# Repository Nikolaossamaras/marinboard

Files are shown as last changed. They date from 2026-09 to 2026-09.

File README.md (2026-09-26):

# MariBoard
>A costum keyboard featuring the anime Character Marin Kitagawa

## What is it
It's a costum keyboard with the thematic of Marin kitagawa from the anime My-dress-up-darling by cloverworks. It's layout is keycool kc84 75% . It includes 84 keys & an oled diplay and it's powered by in raspberry pi pico W , allowing it to connect to the internet in order to display information to the oled display like the Time , date & Weather

## Why i built it?

I really love anime and my favourite character is Marin Kitagawa. I also like electronics and making projects so i sat down and though which will be my next project and i decided on this one a CUSTOM KEYBOARD that is designed with diffrent Marin Kitagawa and dress-up-darling pictures.

## PCB Preview
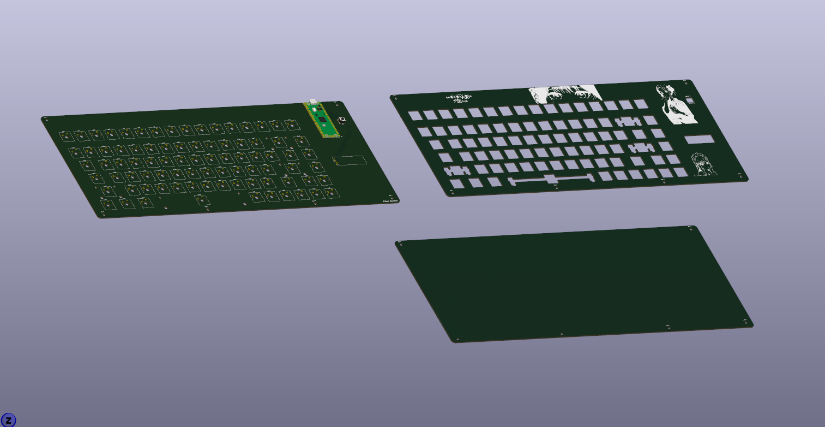
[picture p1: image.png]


---

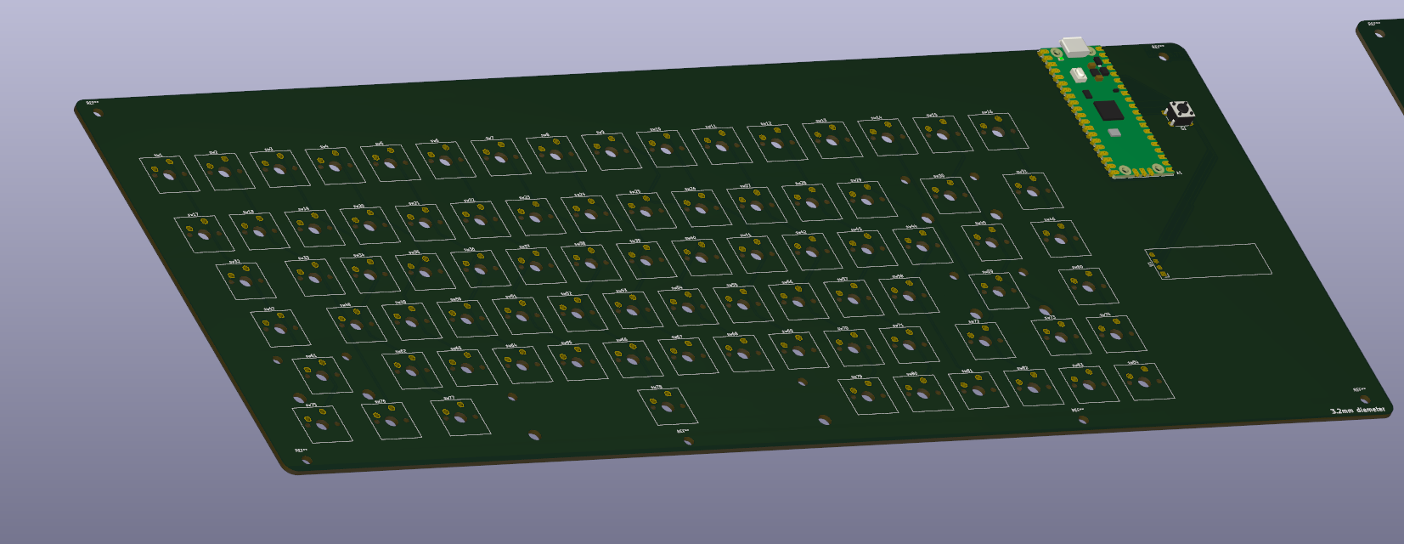
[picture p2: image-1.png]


## Schematic
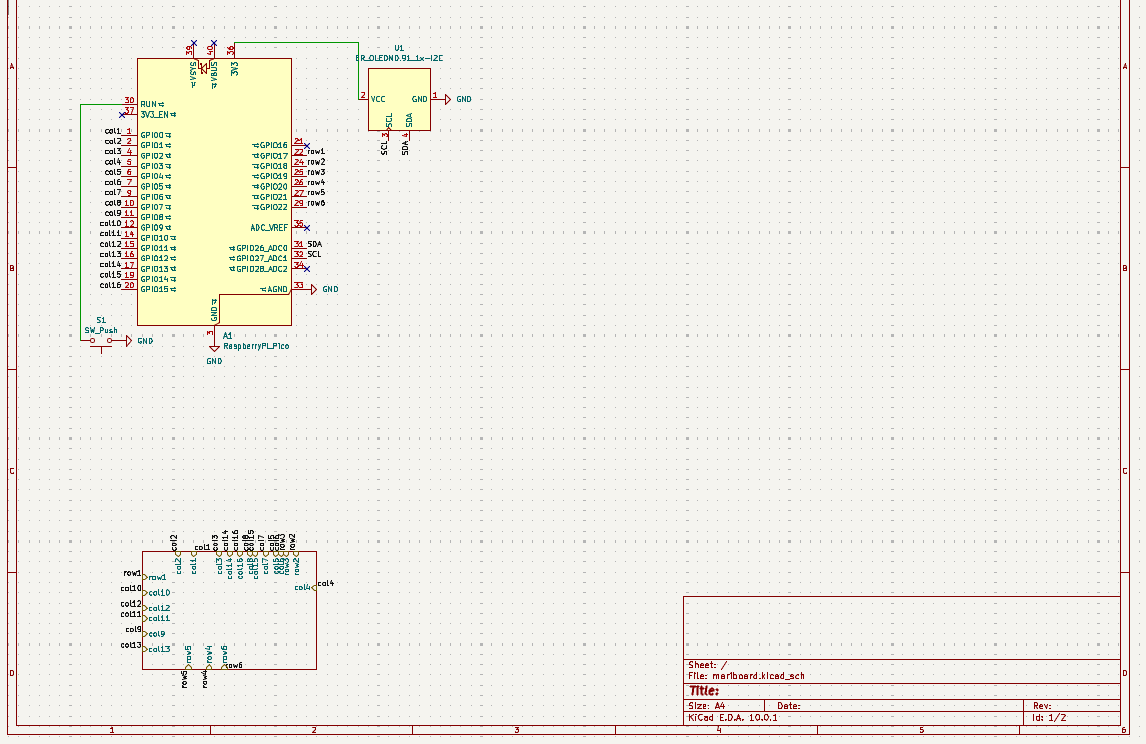
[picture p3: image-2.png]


---

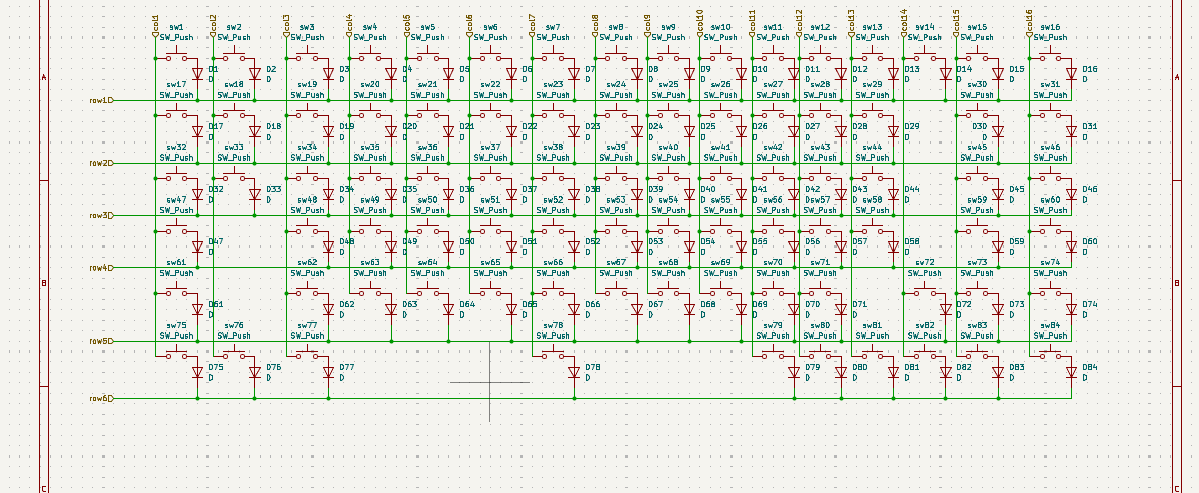
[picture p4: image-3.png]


## CAD



## PCB assembly


## Requirements

| Product | quantity |
| --- | --- |
| OLED Module 128x32 0.91" i2c | 1pc |
| Raspberry Pi Pico W | 1pc |
| 1N4148W diodes | 84pcs |
| costum pcb | 1pc |
| cherry mx switches | 84pcs |
| keycaps | 84 pcs |
| knurled nuts brass m3 | 4pcs |
| 3D printed case | 1pc |

## Tools 

| Tool |
| --- |
| soldering station/iron |
| 3d printer |

## How to assemble it?

### 1st step
your first step is cloning this repo to your Pc so you have all the required files

### 2nd step

Get your pcb , go to a pcb production company and upload the gerber.zip file on their site and order the board

### 3rd step

While you wait for your pcb you can start 3d printing your case which is in Cad folder, there you will see 2 files both are the same one but diffrent format.

> if you don't have a 3d printer you can 3d print it from the same company from which you ordered your pcb

### 4th step 

Now that you have the pcb you will need to solder everything together
if you get an assembled board you wont need to solder the diodes as the are already will come installed , but if you didn't 
your next step is to solder the diodes together on the board like instructed in the schematic

### 5th step
when you finish with the diodes check them with a multimeter to check if they are connected the correct way

### 6th step
now solder the microcontroller and the push button

### 7th step 
solder the oled display in place

### 8th step 
add the switches to the top pcb in order and then put it on top of the middle pcb(main pcb), be careful to align every switch correctly in order the soldering of them to procced smoothly

### 9th step 
add nuts to the 3d printed case at the button 
then place on top of it the pcb's in order (first the bottom , then the main and then the top one) after that pass a screw in each corner mounting hole of the pcb until it's reached the nut , be careful not to damage the main board

### 10th step 
You will need to download the latest .uf2 stable file on Circuitpython for pico W (make sure it's the W not the normal version)

### 11th step
hold the bootsel button on the board while inserting the board to your pc release the button when it's connected **do this step before soldering the top and main pcb together**

### 12th step 

copy the .uf2 file to the microcontroller

the board will reboot and then a drove called ```Circuitpython``` should appear 

### 13th step
Your main program must be named code.py (or main.py) and placed at the root of CIRCUITPY
For libraries , grab the matching version of the CircuitPython Library Bundle and copy the needed .mpy files into a /lib folder on CIRCUITPY

### 14th step
when you upload the code to the drive it should become an input meaning the drive will disapear

## Licence

This project is under the MIT licence

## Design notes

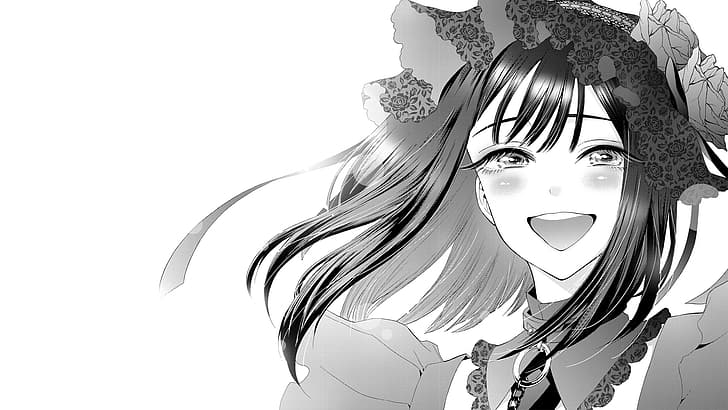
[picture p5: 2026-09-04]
manga-anime-anime-girls-monochrome-sono-bisque-doll-wa-koi-wo-suru-hd-wallpaper-preview.jpg

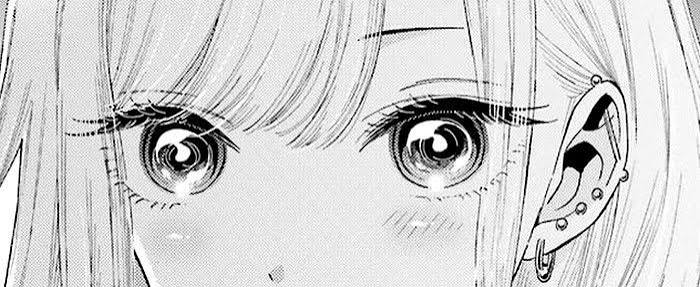
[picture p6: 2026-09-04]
images (1).jpg

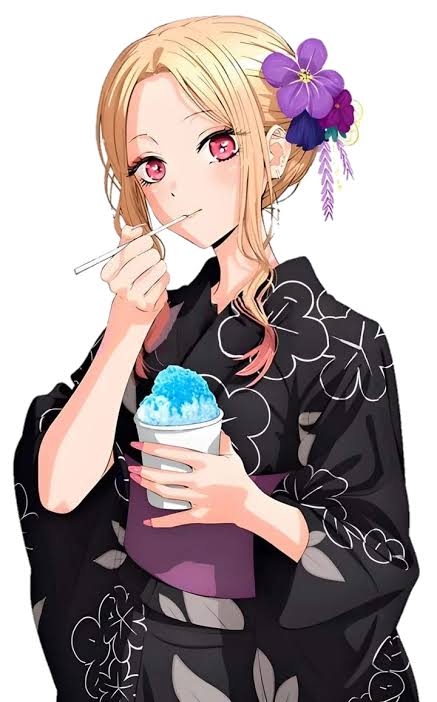
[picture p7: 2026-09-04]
images (2).jpg

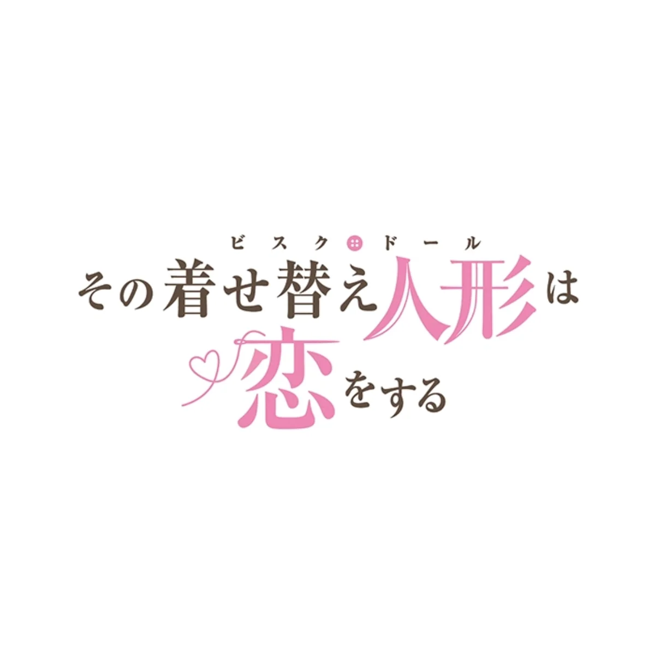
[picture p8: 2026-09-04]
text.png.webp

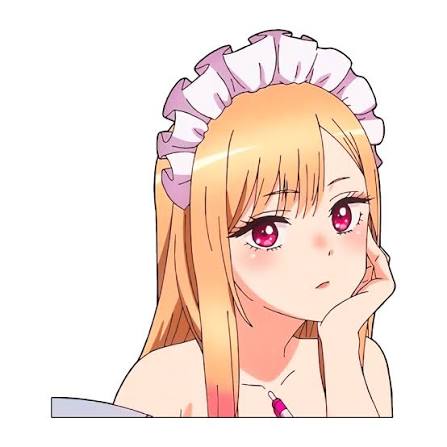
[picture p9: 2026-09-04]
images (3).jpg

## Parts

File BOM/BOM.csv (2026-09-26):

PRODUCT | price | link
OLED Module 0.91" 128x32 - I2C White | 7,90Â $ | https://grobotronics.com/oled-module-0.91-128x32-i2c-white.html
Raspberry Pi Pico W | 9,29Â $ | https://grobotronics.com/raspberry-pi-pico-w-wireless.html?variation_id=16653
1N4148W | $2.06 | https://www.lcsc.com/product-detail/C84367.html?s_z=n_q_x_1N4148W%2520
pcb | $69.28
cherry mx switch | 11.56$ | https://www.temu.com/goods.html?_bg_fs=1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
keycaps | 7.52$ | https://www.temu.com/goods.html?_bg_fs=1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"ld"%2C"US"&_x_ads_channel=impact&_x_ns_mp_value2=&_x_ns_mp_value3=&_x_ns_irmpname=Opera%E2%80%8A&_x_ns_irpid=1943907&_x_vst_scene=adg&_x_sessn_id=80e3cu2gu0&refer_page_name=shopping_cart&refer_page_id=10037_1790422392073_kwofvvozaw&refer_page_sn=10037
knurled nuts brass m3 | 6,57 $ | https://www.temu.com/goods.html?_bg_fs=1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
total | 114.18

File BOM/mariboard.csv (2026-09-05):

Reference | Qty | Value | DNP | Exclude from BOM | Exclude from Board | Exclude from Simulation | Exclude from Position Files | Footprint | Datasheet
A1 | 1 | RaspberryPi_Pico |  |  |  |  | ${EXCLUDE_FROM_POS_FILES} | Module:RaspberryPi_Pico_Common_Unspecified | https://datasheets.raspberrypi.com/pico/pico-datasheet.pdf
D1,D2,D3,D4,D5,D6,D7,D8,D9,D10,D11,D12,D13,D14,D15,D16,D17,D18,D19,D20,D21,D22,D23,D24,D25,D26,D27,D28,D29,D30,D31,D32,D33,D34,D35,D36,D37,D38,D39,D40,D41,D42,D43,D44,D45,D46,D47,D48,D49,D50,D51,D52,D53,D54,D55,D56,D57,D58,D59,D60,D61,D62,D63,D64,D65,D66,D67,D68,D69,D70,D71,D72,D73,D74,D75,D76,D77,D78,D79,D80,D81,D82,D83,D84 | 84 | D |  |  |  |  | ${EXCLUDE_FROM_POS_FILES} | Diode_SMD:D_SOD-123
S1 | 1 | SW_Push |  |  |  |  | ${EXCLUDE_FROM_POS_FILES} | Button_Switch_THT:SW_PUSH_6mm
sw1,sw2,sw3,sw4,sw5,sw6,sw7,sw8,sw9,sw10,sw11,sw12,sw13,sw14,sw15,sw16,sw17,sw18,sw19,sw20,sw21,sw22,sw23,sw24,sw25,sw26,sw27,sw28,sw29,sw31,sw33,sw34,sw35,sw36,sw37,sw38,sw39,sw40,sw41,sw42,sw43,sw44,sw46,sw48,sw49,sw50,sw51,sw52,sw53,sw54,sw55,sw56,sw57,sw58,sw60,sw62,sw63,sw64,sw65,sw66,sw67,sw68,sw69,sw70,sw71,sw73,sw74,sw79,sw80,sw81,sw82,sw83,sw84 | 73 | SW_Push |  |  |  |  | ${EXCLUDE_FROM_POS_FILES} | Button_Switch_Keyboard:SW_Cherry_MX_1.00u_PCB
sw30 | 1 | SW_Push |  |  |  |  | ${EXCLUDE_FROM_POS_FILES} | Button_Switch_Keyboard:SW_Cherry_MX_2.00u_PCB
sw32,sw45 | 2 | SW_Push |  |  |  |  | ${EXCLUDE_FROM_POS_FILES} | Button_Switch_Keyboard:SW_Cherry_MX_1.50u_PCB
sw47,sw72 | 2 | SW_Push |  |  |  |  | ${EXCLUDE_FROM_POS_FILES} | Button_Switch_Keyboard:SW_Cherry_MX_1.75u_PCB
sw59,sw61 | 2 | SW_Push |  |  |  |  | ${EXCLUDE_FROM_POS_FILES} | Button_Switch_Keyboard:SW_Cherry_MX_2.25u_PCB
sw75,sw76,sw77 | 3 | SW_Push |  |  |  |  | ${EXCLUDE_FROM_POS_FILES} | Button_Switch_Keyboard:SW_Cherry_MX_1.25u_PCB
sw78 | 1 | SW_Push |  |  |  |  | ${EXCLUDE_FROM_POS_FILES} | Button_Switch_Keyboard:SW_Cherry_MX_6.25u_PCB
U1 | 1 | ER_OLEDM0.91_1x-I2C |  |  |  |  | ${EXCLUDE_FROM_POS_FILES} | Display:ER_OLEDM0.91_1x-I2C | https://www.buydisplay.com/download/manual/ER-OLEDM0.91-1_Datasheet.pdf

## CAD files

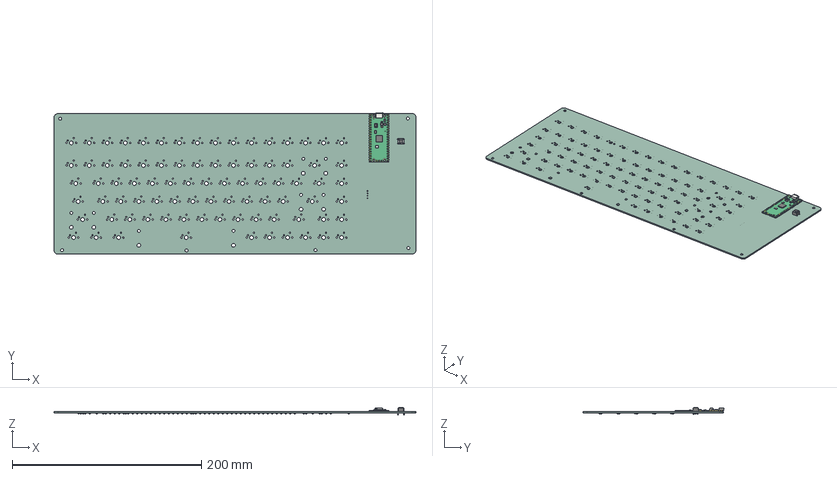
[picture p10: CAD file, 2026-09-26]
Cad/mainv2.step
382.7 x 149.6 x 7.80 mm
SW_PUSH_6mm
RaspberryPi_Pico_Module_KiCad
D_SOD-123 x 84
mariboard_PCB

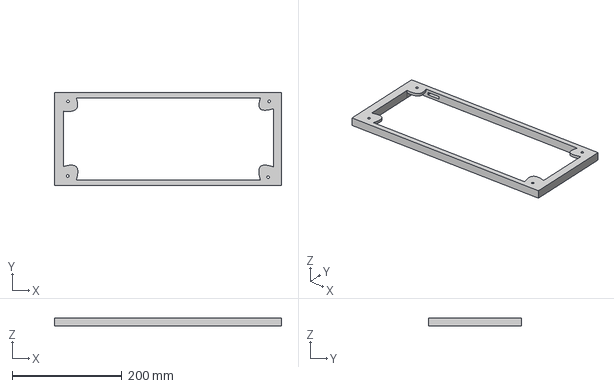
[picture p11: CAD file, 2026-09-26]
Cad/case keyboard mariboard.step
413.0 x 169.0 x 15.0 mm

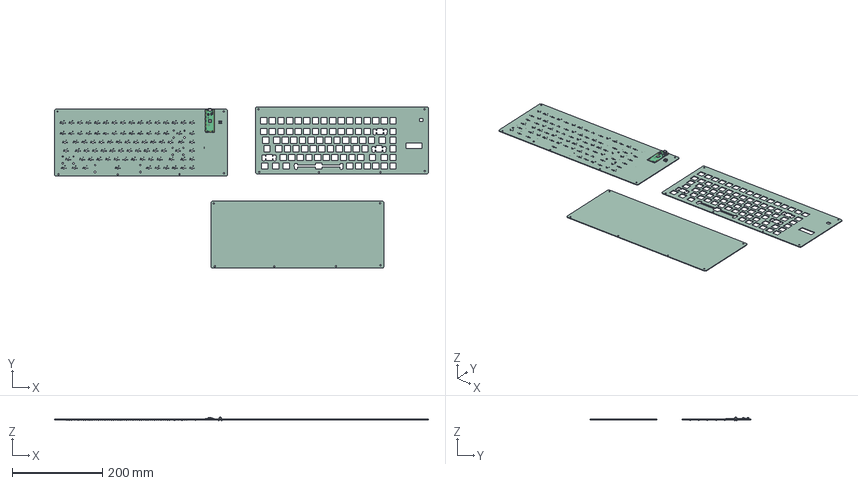
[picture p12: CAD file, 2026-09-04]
Cad/mariboard.step
827.0 x 356.9 x 7.80 mm
SW_PUSH_6mm
RaspberryPi_Pico_Module_KiCad
D_SOD-123 x 84
marCF42_PCB_1
marCF42_PCB_2
marCF42_PCB_3

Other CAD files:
Cad/case keyboard mariboard.f3d
Cad/pcb_assembly.f3z

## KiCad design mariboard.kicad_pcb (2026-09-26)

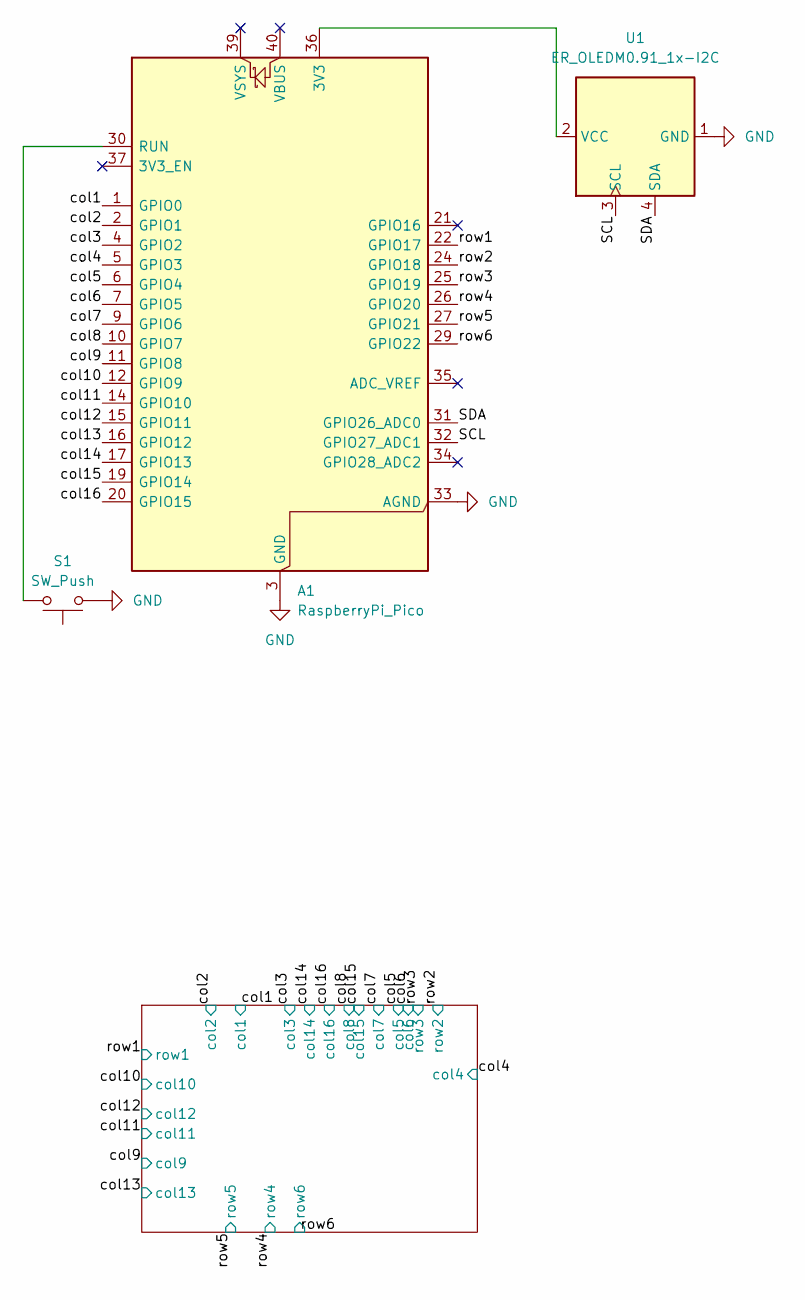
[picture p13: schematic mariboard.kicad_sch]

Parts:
A1: RaspberryPi_Pico; RaspberryPi_Pico_Common_Unspecified
S1: SW_Push; SW_PUSH_6mm
U1: ER_OLEDM0.91_1x-I2C

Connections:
/SCL: A1.32 (GPIO27_ADC1), U1.3 (SCL)
/SDA: A1.31 (GPIO26_ADC0), U1.4 (SDA)
/col1: A1.1 (GPIO0); also elsewhere on the board
/col2: A1.2 (GPIO1); also elsewhere on the board
/col3: A1.4 (GPIO2); also elsewhere on the board
/col4: A1.5 (GPIO3); also elsewhere on the board
/col5: A1.6 (GPIO4); also elsewhere on the board
/col6: A1.7 (GPIO5); also elsewhere on the board
/col7: A1.9 (GPIO6); also elsewhere on the board
/col8: A1.10 (GPIO7); also elsewhere on the board
/col9: A1.11 (GPIO8); also elsewhere on the board
/col10: A1.12 (GPIO9); also elsewhere on the board
/col11: A1.14 (GPIO10); also elsewhere on the board
/col12: A1.15 (GPIO11); also elsewhere on the board
/col13: A1.16 (GPIO12); also elsewhere on the board
/col14: A1.17 (GPIO13); also elsewhere on the board
/col15: A1.19 (GPIO14); also elsewhere on the board
/col16: A1.20 (GPIO15); also elsewhere on the board
/row1: A1.22 (GPIO17); also elsewhere on the board
/row2: A1.24 (GPIO18); also elsewhere on the board
/row3: A1.25 (GPIO19); also elsewhere on the board
/row4: A1.26 (GPIO20); also elsewhere on the board
/row5: A1.27 (GPIO21); also elsewhere on the board
/row6: A1.29 (GPIO22); also elsewhere on the board
GND: A1.3 (GND), A1.8 (GND), A1.13 (GND), A1.18 (GND), A1.23 (GND), A1.28 (GND), A1.33 (AGND), A1.38 (GND), S1.1, U1.1 (GND)
unnamed: A1.36 (3V3), U1.2 (VCC)
unnamed: A1.30 (RUN), S1.2

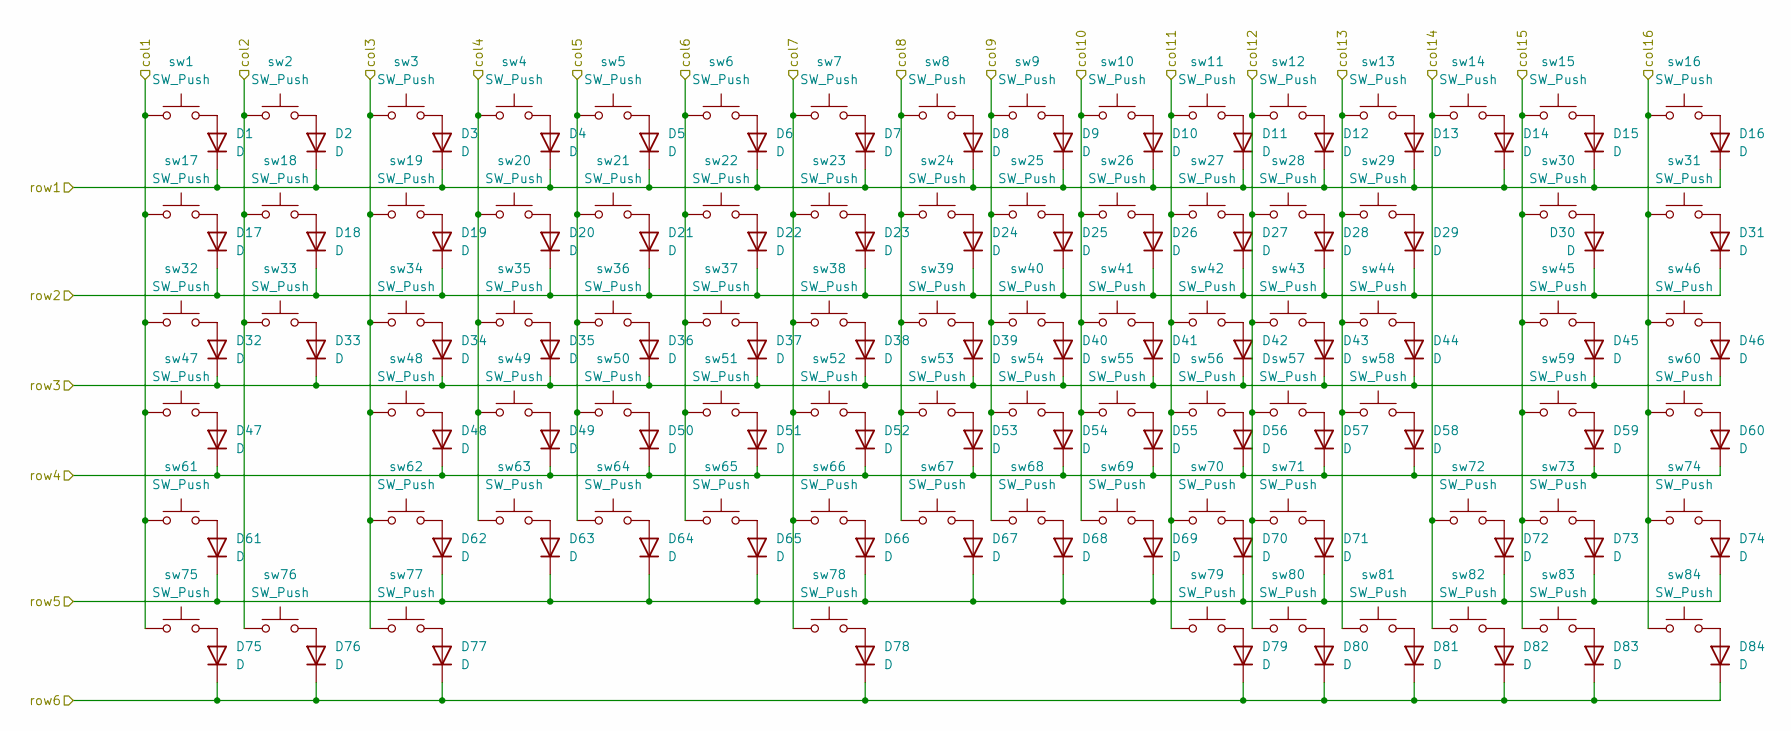
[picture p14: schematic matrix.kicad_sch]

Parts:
D1, D2, D3, D4, D5, D6, D7, D8, D9, D10, D11, D12, D13, D14, D15, D16, D17, D18, D19, D20, D21, D22, D23, D24, D25, D26, D27, D28, D29, D30, D31, D32, D33, D34, D35, D36, D37, D38, D39, D40, D41, D42, D43, D44, D45, D46, D47, D48, D49, D50, D51, D52, D53, D54, D55, D56, D57, D58, D59, D60, D61, D62, D63, D64, D65, D66, D67, D68, D69, D70, D71, D72, D73, D74, D75, D76, D77, D78, D79, D80, D81, D82, D83, D84: D; D_SOD-123
sw1, sw2, sw3, sw4, sw5, sw6, sw7, sw8, sw9, sw10, sw11, sw12, sw13, sw14, sw15, sw16, sw17, sw18, sw19, sw20, sw21, sw22, sw23, sw24, sw25, sw26, sw27, sw28, sw29, sw31, sw33, sw34, sw35, sw36, sw37, sw38, sw39, sw40, sw41, sw42, sw43, sw44, sw46, sw48, sw49, sw50, sw51, sw52, sw53, sw54, sw55, sw56, sw57, sw58, sw60, sw62, sw63, sw64, sw65, sw66, sw67, sw68, sw69, sw70, sw71, sw73, sw74, sw79, sw80, sw81, sw82, sw83, sw84: SW_Push; SW_Cherry_MX_1.00u_PCB
sw30: SW_Push; SW_Cherry_MX_2.00u_PCB
sw32, sw45: SW_Push; SW_Cherry_MX_1.50u_PCB
sw47, sw72: SW_Push; SW_Cherry_MX_1.75u_PCB
sw59, sw61: SW_Push; SW_Cherry_MX_2.25u_PCB
sw75, sw76, sw77: SW_Push; SW_Cherry_MX_1.25u_PCB
sw78: SW_Push; SW_Cherry_MX_6.25u_PCB

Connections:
/col1: sw1.1, sw17.1, sw32.1, sw47.1, sw61.1, sw75.1; also elsewhere on the board
/col2: sw2.1, sw18.1, sw33.1, sw76.1; also elsewhere on the board
/col3: sw3.1, sw19.1, sw34.1, sw48.1, sw62.1, sw77.1; also elsewhere on the board
/col4: sw4.1, sw20.1, sw35.1, sw49.1, sw63.1; also elsewhere on the board
/col5: sw5.1, sw21.1, sw36.1, sw50.1, sw64.1; also elsewhere on the board
/col6: sw6.1, sw22.1, sw37.1, sw51.1, sw65.1; also elsewhere on the board
/col7: sw7.1, sw23.1, sw38.1, sw52.1, sw66.1, sw78.1; also elsewhere on the board
/col8: sw8.1, sw24.1, sw39.1, sw53.1, sw67.1; also elsewhere on the board
/col9: sw9.1, sw25.1, sw40.1, sw54.1, sw68.1; also elsewhere on the board
/col10: sw10.1, sw26.1, sw41.1, sw55.1, sw69.1; also elsewhere on the board
/col11: sw11.1, sw27.1, sw42.1, sw56.1, sw70.1, sw79.1; also elsewhere on the board
/col12: sw12.1, sw28.1, sw43.1, sw57.1, sw71.1, sw80.1; also elsewhere on the board
/col13: sw13.1, sw29.1, sw44.1, sw58.1, sw81.1; also elsewhere on the board
/col14: sw14.1, sw72.1, sw82.1; also elsewhere on the board
/col15: sw15.1, sw30.1, sw45.1, sw59.1, sw73.1, sw83.1; also elsewhere on the board
/col16: sw16.1, sw31.1, sw46.1, sw60.1, sw74.1, sw84.1; also elsewhere on the board
/row1: D1.1 (K), D2.1 (K), D3.1 (K), D4.1 (K), D5.1 (K), D6.1 (K), D7.1 (K), D8.1 (K), D9.1 (K), D10.1 (K), D11.1 (K), D12.1 (K), D13.1 (K), D14.1 (K), D15.1 (K), D16.1 (K); also elsewhere on the board
/row2: D17.1 (K), D18.1 (K), D19.1 (K), D20.1 (K), D21.1 (K), D22.1 (K), D23.1 (K), D24.1 (K), D25.1 (K), D26.1 (K), D27.1 (K), D28.1 (K), D29.1 (K), D30.1 (K), D31.1 (K); also elsewhere on the board
/row3: D32.1 (K), D33.1 (K), D34.1 (K), D35.1 (K), D36.1 (K), D37.1 (K), D38.1 (K), D39.1 (K), D40.1 (K), D41.1 (K), D42.1 (K), D43.1 (K), D44.1 (K), D45.1 (K), D46.1 (K); also elsewhere on the board
/row4: D47.1 (K), D48.1 (K), D49.1 (K), D50.1 (K), D51.1 (K), D52.1 (K), D53.1 (K), D54.1 (K), D55.1 (K), D56.1 (K), D57.1 (K), D58.1 (K), D59.1 (K), D60.1 (K); also elsewhere on the board
/row5: D61.1 (K), D62.1 (K), D63.1 (K), D64.1 (K), D65.1 (K), D66.1 (K), D67.1 (K), D68.1 (K), D69.1 (K), D70.1 (K), D71.1 (K), D72.1 (K), D73.1 (K), D74.1 (K); also elsewhere on the board
/row6: D75.1 (K), D76.1 (K), D77.1 (K), D78.1 (K), D79.1 (K), D80.1 (K), D81.1 (K), D82.1 (K), D83.1 (K), D84.1 (K); also elsewhere on the board
unnamed: D1.2 (A), sw1.2
unnamed: D2.2 (A), sw2.2
unnamed: D3.2 (A), sw3.2
unnamed: D4.2 (A), sw4.2
unnamed: D5.2 (A), sw5.2
unnamed: D6.2 (A), sw6.2
unnamed: D7.2 (A), sw7.2
unnamed: D8.2 (A), sw8.2
unnamed: D9.2 (A), sw9.2
unnamed: D10.2 (A), sw10.2
unnamed: D11.2 (A), sw11.2
unnamed: D12.2 (A), sw12.2
unnamed: D13.2 (A), sw13.2
unnamed: D14.2 (A), sw14.2
unnamed: D15.2 (A), sw15.2
unnamed: D16.2 (A), sw16.2
unnamed: D17.2 (A), sw17.2
unnamed: D18.2 (A), sw18.2
unnamed: D19.2 (A), sw19.2
unnamed: D20.2 (A), sw20.2
unnamed: D21.2 (A), sw21.2
unnamed: D22.2 (A), sw22.2
unnamed: D23.2 (A), sw23.2
unnamed: D24.2 (A), sw24.2
unnamed: D25.2 (A), sw25.2
unnamed: D26.2 (A), sw26.2
unnamed: D27.2 (A), sw27.2
unnamed: D28.2 (A), sw28.2
unnamed: D29.2 (A), sw29.2
unnamed: D30.2 (A), sw30.2
unnamed: D31.2 (A), sw31.2
unnamed: D32.2 (A), sw32.2
unnamed: D33.2 (A), sw33.2
unnamed: D34.2 (A), sw34.2
unnamed: D35.2 (A), sw35.2
unnamed: D36.2 (A), sw36.2
unnamed: D37.2 (A), sw37.2
unnamed: D38.2 (A), sw38.2
unnamed: D39.2 (A), sw39.2
unnamed: D40.2 (A), sw40.2
unnamed: D41.2 (A), sw41.2
unnamed: D42.2 (A), sw42.2
unnamed: D43.2 (A), sw43.2
unnamed: D44.2 (A), sw44.2
unnamed: D45.2 (A), sw45.2
unnamed: D46.2 (A), sw46.2
unnamed: D47.2 (A), sw47.2
unnamed: D48.2 (A), sw48.2
unnamed: D49.2 (A), sw49.2
unnamed: D50.2 (A), sw50.2
unnamed: D51.2 (A), sw51.2
unnamed: D52.2 (A), sw52.2
unnamed: D53.2 (A), sw53.2
unnamed: D54.2 (A), sw54.2
unnamed: D55.2 (A), sw55.2
unnamed: D56.2 (A), sw56.2
unnamed: D57.2 (A), sw57.2
unnamed: D58.2 (A), sw58.2
unnamed: D59.2 (A), sw59.2
unnamed: D60.2 (A), sw60.2
unnamed: D61.2 (A), sw61.2
unnamed: D62.2 (A), sw62.2
unnamed: D63.2 (A), sw63.2
unnamed: D64.2 (A), sw64.2
unnamed: D65.2 (A), sw65.2
unnamed: D66.2 (A), sw66.2
unnamed: D67.2 (A), sw67.2
unnamed: D68.2 (A), sw68.2
unnamed: D69.2 (A), sw69.2
unnamed: D70.2 (A), sw70.2
unnamed: D71.2 (A), sw71.2
unnamed: D72.2 (A), sw72.2
unnamed: D73.2 (A), sw73.2
unnamed: D74.2 (A), sw74.2
unnamed: D75.2 (A), sw75.2
unnamed: D76.2 (A), sw76.2
unnamed: D77.2 (A), sw77.2
unnamed: D78.2 (A), sw78.2
unnamed: D79.2 (A), sw79.2
unnamed: D80.2 (A), sw80.2
unnamed: D81.2 (A), sw81.2
unnamed: D82.2 (A), sw82.2
unnamed: D83.2 (A), sw83.2
unnamed: D84.2 (A), sw84.2

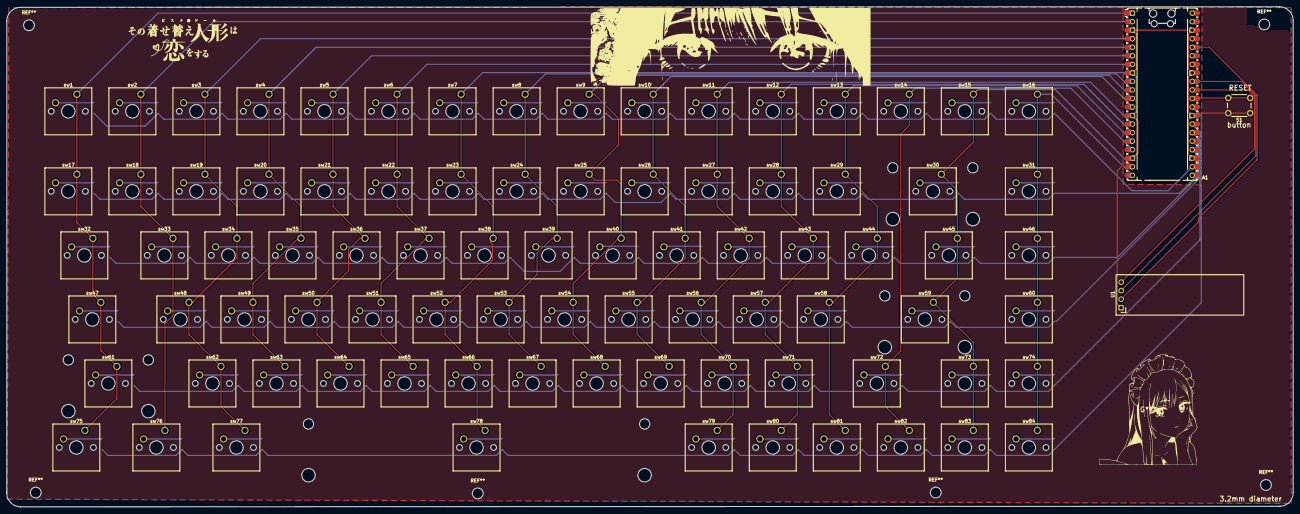
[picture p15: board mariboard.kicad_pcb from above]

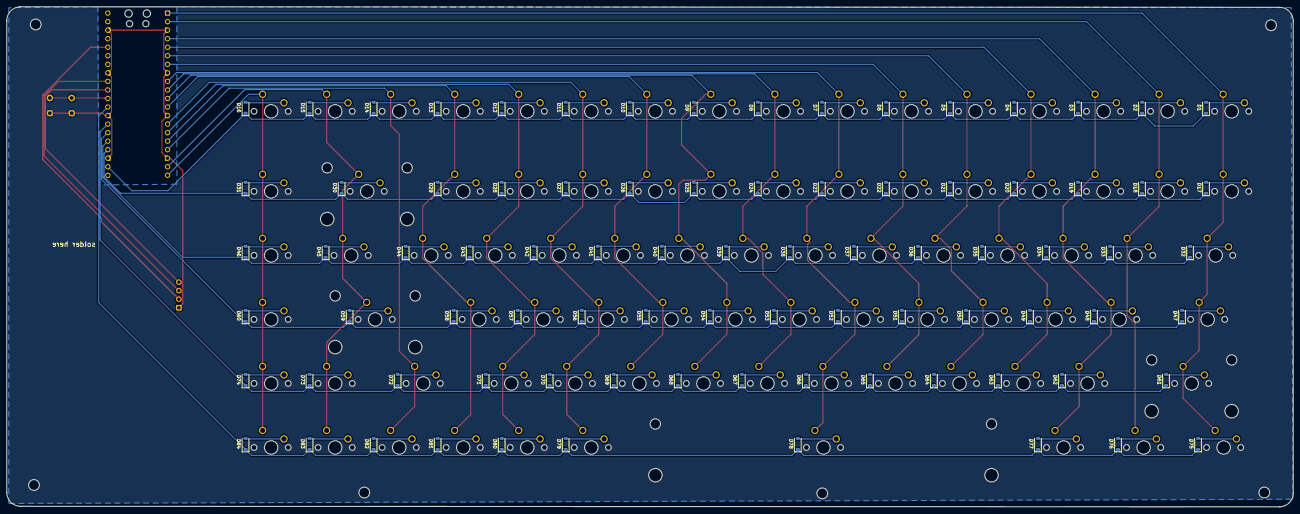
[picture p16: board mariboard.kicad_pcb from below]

Board: 2 copper layers, 382.7 x 148.8 mm, 171 parts (84 on the bottom side), 111 nets.

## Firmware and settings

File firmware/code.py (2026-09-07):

import board
import digitalio
import usb_hid
import time
import busio
import displayio
import terminalio
import wifi
import socketpool
import ssl
import os
import rtc
import adafruit_requests
import adafruit_ntp
import adafruit_displayio_ssd1306

from adafruit_display_text import label
from adafruit_hid.keyboard import Keyboard
from adafruit_hid.keycode import Keycode

#Configuration

WIFI_SSID = os.getenv("WIFI_SSID") # change this in your .env file
WIFI_PASSWORD = os.getenv("WIFI_PASSWORD") # change this in your .env file
WIFI_TIMEOUT = 8  

UTC_OFFSET = 3

OPENWEATHER_API_KEY = os.getenv("OPENWEATHER_API_KEY") # change this in your .env file
OPENWEATHER_CITY = "Athens,GR" # change this to your city
WEATHER_REFRESH_TIME = 900 

NTP_REFRESH_RATE = 3600

ANIMATION_FRAME_DIR= "/marin"
ANIMATION_FRAME_COUNT = 56
ANIMATION_FRAME_INTERVAL = 0.15

OLED_WIDTH = 128
OLED_HEIGHT = 32
OLED_I2C_ADDRESS = 0x3C
SDA_PIN = board.GP26
SCL_PIN = board.GP27

COL_PINS =[
    board.GP0,
    board.GP1,
    board.GP2,
    board.GP3,
    board.GP4,
    board.GP5,
    board.GP6,
    board.GP7,
    board.GP8,
    board.GP9,
    board.GP10,
    board.GP11,
    board.GP12,
    board.GP13,
    board.GP14,
    board.GP15
]#columns 1-16

ROW_PINS = [
    board.GP17,
    board.GP18,
    board.GP19,
    board.GP20,
    board.GP21,
    board.GP22
]#rows 1-6

columns =[]

for pin in COL_PINS:
    col = digitalio.DigitalInOut(pin)
    col.direction = digitalio.Direction.OUTPUT
    col.value = False
    columns.append(col)
rows = []

for pin in ROW_PINS:
    row = digitalio.DigitalInOut(pin)
    row.direction = digitalio.Direction.INPUT
    row.pull = digitalio.Pull.DOWN
    rows.append(row)


displayio.release_displays()
i2c= busio.I2C(SCL_PIN,SDA_PIN)
display_bus = displayio.I2CDisplay(i2c, device_address=OLED_I2C_ADDRESS)
display = adafruit_displayio_ssd1306.SSD1306(display_bus,width=OLED_WIDTH,height=OLED_HEIGHT)


# PAGE 1


_reported_missing = set()
animation_group = displayio.Group()
_current_frame_bitmap = None
_current_frame_tilegrid = None

def load_animation_frame(index):
    global _current_frame_bitmap, _current_frame_tilegrid

    path = "{}/frame{:03d}.bmp".format(ANIMATION_FRAME_DIR, index + 1)
    try:
        bitmap = displayio.OnDiskBitmap(path)
    except OSError:
        if path not in _reported_missing:
            print("Failed to load frame:",path)
            _reported_missing.add(path)
        return

    tilegrid = displayio.TileGrid(bitmap, pixel_shader=bitmap.pixel_shader)

    if _current_frame_tilegrid is not None:
        animation_group.remove(_current_frame_tilegrid)

    animation_group.append(tilegrid)
    _current_frame_bitmap = bitmap
    _current_frame_tilegrid = tilegrid

# Page 2
clock_group = displayio.Group()
clock_time_label = label.Label(terminalio.FONT, text="--:--:--",x=25,y=8,scale =1)
clock_group.append(clock_time_label)
clock_date_label = label.Label(terminalio.FONT, text="--/--/----",x=25,y=20,scale =1)
clock_group.append(clock_date_label)

# Page 3
weather_group = displayio.Group()
weather_temp_label = label.Label(terminalio.FONT, text="--°C",x=5,y=8,scale =1)
weather_group.append(weather_temp_label)
weather_cond_label = label.Label(terminalio.FONT,text="---",x=60,y=8,scale =1)
weather_group.append(weather_cond_label)
weather_hum_label = label.Label(terminalio.FONT,text="--%",x=5,y=22,scale =1)
weather_group.append(weather_hum_label)

PAGES =[animation_group, clock_group, weather_group]
current_page_index = 0
display.root_group = PAGES[current_page_index]

# WIFI

wifi_connected = False
requests_session = None
ntp = None

try:
    wifi.radio.connect(WIFI_SSID, WIFI_PASSWORD, timeout=WIFI_TIMEOUT)
    wifi_connected = True
except (ConnectionError, OSError):
    wifi_connected = False

if wifi_connected:
    pool = socketpool.SocketPool(wifi.radio)
    requests_session = adafruit_requests.Session(pool, ssl.create_default_context())
    ntp = adafruit_ntp.NTP(pool, tz_offset=UTC_OFFSET)

# States

now=time.monotonic()

last_animation_tick = now
animation_frame_index = 0

last_clock_update = 0
last_ntp_sync = 0
time_synced = False

last_weather_fetch = 0
weather_ok = False

WEEKDAYS = ["Mon","Tue","Wed","Thu","Fri","Sat","Sun"]

def sync_ntp_time():
    global time_synced
    if not  wifi_connected or ntp is None:
        return
    try:
        rtc.RTC().datetime = ntp.datetime
        time_synced = True
    except(ValueError,OSError):
        time_synced = False

def fetch_weather():
    global weather_ok
    if not wifi_connected or requests_session is None:
        weather_ok = False
        return None
    url=(
        "https://api.openweathermap.org/data/2.5/weather"
        "?q={city}&appid={key}&units=metric"
    ).format(city=OPENWEATHER_CITY,key=OPENWEATHER_API_KEY)
    try:
        response = requests_session.get(url,timeout=5)
        data = response.json()
        response.close()
        weather_ok = True
        return{
            "temp": data["main"]["temp"],
            "humidity": data["main"]["humidity"],
            "condition": data["weather"][0]["main"]
        }
    except (OSError,ValueError,KeyError):
        weather_ok = False
        return None

def update_clock_display():
    t = time.localtime()
    time_str = "{:02d}:{:02d}:{:02d}".format(t.tm_hour,t.tm_min,t.tm_sec)
    date_str = "{:02d}/{:02d}/{:04d}".format(t.tm_mday,t.tm_mon,t.tm_year)

    if clock_time_label.text != time_str:
        clock_time_label.text = time_str
    if clock_date_label.text != date_str:
        clock_date_label.text = date_str

def update_weather_display(weather):
    if weather is None:
        weather_cond_label.text = "Offline"
        return
    weather_temp_label.text = "{:.1f}C".format(weather["temp"])
    weather_cond_label.text = weather["condition"]
    weather_hum_label.text = "Hum: {}%".format(weather["humidity"])

def switch_page():
    global current_page_index
    current_page_index = (current_page_index + 1) % len(PAGES)
    display.root_group = PAGES[current_page_index]



# Keyboard mapping
KEYMAP = {
    (0,0):Keycode.ESCAPE,
    (0,1):Keycode.F1,
    (0,2):Keycode.F2,
    (0,3):Keycode.F3,
    (0,4):Keycode.F4,
    (0,5):Keycode.F5,
    (0,6):Keycode.F6,
    (0,7):Keycode.F7,
    (0,8):Keycode.F8,
    (0,9):Keycode.F9,
    (0,10):Keycode.F10,
    (0,11):Keycode.F11,
    (0,12):Keycode.F12,
    (0,13):Keycode.PRINT_SCREEN,
    (0,14):Keycode.SCROLL_LOCK,
    (0,15):Keycode.DELETE,
    (1,0):Keycode.GRAVE_ACCENT,
    (1,1):Keycode.ONE,
    (1,2):Keycode.TWO,
    (1,3):Keycode.THREE,
    (1,4):Keycode.FOUR,
    (1,5):Keycode.FIVE,
    (1,6):Keycode.SIX,
    (1,7):Keycode.SEVEN,
    (1,8):Keycode.EIGHT,
    (1,9):Keycode.NINE,
    (1,10):Keycode.ZERO,
    (1,11):Keycode.MINUS,
    (1,12):Keycode.EQUALS,
    (1,14):Keycode.BACKSPACE,
    (1,15):Keycode.HOME,
    (2,0):Keycode.TAB,
    (2,1):Keycode.Q,
    (2,2):Keycode.W,
    (2,3):Keycode.E,
    (2,4):Keycode.R,
    (2,5):Keycode.T,
    (2,6):Keycode.Y,
    (2,7):Keycode.U,
    (2,8):Keycode.I,
    (2,9):Keycode.O,
    (2,10):Keycode.P,
    (2,11):Keycode.LEFT_BRACKET,
    (2,12):Keycode.RIGHT_BRACKET,
    (2,14):Keycode.BACKSLASH,
    (2,15):Keycode.PAGE_UP,
    (3,0):Keycode.CAPS_LOCK,
    (3,2):Keycode.A,
    (3,3):Keycode.S,
    (3,4):Keycode.D,
    (3,5):Keycode.F,
    (3,6):Keycode.G,
    (3,7):Keycode.H,
    (3,8):Keycode.J,
    (3,9):Keycode.K,
    (3,10):Keycode.L,
    (3,11):Keycode.SEMICOLON,
    (3,12):Keycode.QUOTE,
    (3,14):Keycode.ENTER,
    (3,15):Keycode.PAGE_DOWN,
    (4,0):Keycode.LEFT_SHIFT,
    (4,2):Keycode.Z,
    (4,3):Keycode.X,
    (4,4):Keycode.C,
    (4,5):Keycode.V,
    (4,6):Keycode.B,
    (4,7):Keycode.N,
    (4,8):Keycode.M,
    (4,9):Keycode.COMMA,
    (4,10):Keycode.PERIOD,
    (4,11):Keycode.FORWARD_SLASH,
    (4,13):Keycode.RIGHT_SHIFT,
    (4,14):Keycode.UP_ARROW,
    (4,15):Keycode.END,
    (5,0):Keycode.LEFT_CONTROL,
    (5,1):Keycode.LEFT_GUI,
    (5,11):"FN",
    (5,12):Keycode.RIGHT_CONTROL,
    (5,13):Keycode.LEFT_ARROW,
    (5,14):Keycode.DOWN_ARROW,
    (5,15):Keycode.RIGHT_ARROW
}

kbd = Keyboard(usb_hid.devices)
pressed_state = {}

def scan_matrix():
    for col_index, col in enumerate(columns):
        col.value = True
        for row_index, row in enumerate(rows):
            key = (row_index , col_index)
            is_pressed = row.value

            was_pressed = pressed_state.get(key,False)

            if key in KEYMAP:
                keycode = KEYMAP[key]

                if is_pressed and not was_pressed:
                    if keycode =="FN":
                        switch_page()
                    else:
                        kbd.press(keycode)

                elif not is_pressed and was_pressed:
                    if keycode !="FN":
                        kbd.release(keycode)

            pressed_state[key] = is_pressed

        col.value = False

# Main loop
while True:

    now = time.monotonic()

    scan_matrix()

    if current_page_index == 0 and (now-last_animation_tick) >= ANIMATION_FRAME_INTERVAL:
        load_animation_frame(animation_frame_index)
        animation_frame_index = (animation_frame_index + 1) % ANIMATION_FRAME_COUNT
        last_animation_tick = now

    if wifi_connected and (now - last_ntp_sync) >= NTP_REFRESH_RATE:
        sync_ntp_time()
        last_ntp_sync = now

    if current_page_index == 1 and (now - last_clock_update) >= 1:
        update_clock_display()
        last_clock_update = now

    if current_page_index == 2 and (now - last_weather_fetch) >= WEATHER_REFRESH_TIME:
        weather_data = fetch_weather()
        if current_page_index == 2:
            update_weather_display(weather_data)
        last_weather_fetch = now

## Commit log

2026-09-07 gerber files update
    [mariboard-B_Cu.gbr, mariboard-B_Mask.gbr, mariboard-B_Paste.gbr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]
2026-09-13 cherry mx switch
    [BOM.csv]
2026-09-26 update BOM
    [BOM.csv, BOM.xlsx]
2026-09-26 BOM update
    [BOM.csv, BOM.xlsx]
2026-09-26 Updated Case + BOM
    [BOM.csv, BOM.xlsx, mainv2.step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]
2026-09-26 Updated Case
    [case keyboard mariboard.f3d, case keyboard mariboard.step]
2026-09-26 Add PCB assembly section to README
    Added PCB assembly section with an image.
2026-09-26 Replace CAD image in README
    Updated CAD section with a new image and removed the old one.
